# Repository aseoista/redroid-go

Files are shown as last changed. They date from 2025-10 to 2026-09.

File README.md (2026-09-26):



> [!WARNING]
> In every commit and release before [0a4a438](https://github.com/aseoista/redroid-go/commit/0a4a438) (including **v1.0.2**), transistor **Q2** was connected in reverse. You should **build the device from the _master_ branch**, where this is fixed, until a new release is issued.

REDROID-GO is an open-source, custom-designed handheld gaming console inspired by the original ODROID-GO. This project enhances the original (discontinued) design with modern features, while maintaining as much as possible software compatibility.

|  | redroid_go_front | redroid_go_bottom |
| :---: | :---: | :---: |
| Full Build | PCB Front  | PCB Back | 

## Features
- **USB-C Connector** – Modern power and data connectivity.
- **Optional IPS Display** – Upgrade to a vibrant IPS screen instead of the standard TFT.
- **High Software Compatibility** – Works with ODROID-GO software, but unfortunately some patches may be required, see below.
- **Fully Open-Source** ❤️ – Schematics, PCB, and BOM included!

## Repository Contents
- **KiCad Project** – Includes schematic, PCB design, and layout.
- **FreeCAD Project** – Design of the shell.
- **Bill of Materials (BOM)** – All of the PCB components are sourced from LCSC. Other components, such as the display, speaker, battery, buttons need to be bought separately.

### Branching Structure
The _master_ branch contains the latest, **unstable** version of the project, which has not been manufactured or tested yet. If you are looking for a stable and tested version, please refer to the **releases** section, where you can find previous working versions of REDROID-GO.

## Compatibility
The base idea is to keep the project as much software-compatible as possible to the original ODROID-GO. There are some caveats though:
- New ESP32-WROVERs require the setting `CONFIG_INT_WDT` set to `y` in ESP-IDF.
- When using the IPS display, the commands to initialize it should include an additional `0x21`. This is because even if the IPS display uses the same driver IC as the TFT one, by default the colors are inverted.

## Hardware Fabrication
For a full guide to build the device, refer to [BUILDING.md](BUILDING.md)!
### Ordering the PCB
You can order the PCB directly from the `gerber.zip` release artifact using any common PCB manufacturer.<br>
Specs for ordering:
- **Thickness:** 1.6 mm, **required** to make it fit in the case
- **Finish:** ENIG is **strongly recommended**. ENIG provides a flatter and more durable pad surface than HASL, which ensures more consistent readings from the membrane buttons over time.

### Soldering the Components
All components can be soldered by hand.

**Tips**
- A regular soldering iron is sufficient — use a **thin tip** for finer control
- Apply **no-clean flux or thermal flux** to ease solder flow and avoid bridges
- **Start with the USB-C connector and the display connector** — they are the most difficult parts to solder; then proceed with the remaining components
- A **desoldering braid** can be very useful to wick away any excess solder or to correct bridges
- When done soldering, clean the PCB with **isopropyl alcohol (≥90% IPA)**, especially around the buttons’ pads, using a brush or lint-free wipe; let it dry fully before powering

### Shell
The shell can be 3D printed using the STL files contained in the `case.zip` release artifact.

## Software
This device can be programmed like any other ESP32-based board.<br>
A customized bootloader is available in this [fork](https://github.com/aseoista/odroid-go-multi-firmware) of the original [odroid-go-multi-firmware](https://github.com/ducalex/odroid-go-multi-firmware).  
For emulation, the recommended firmware is this [fork](https://github.com/aseoista/retro-go) of [retro-go](https://github.com/ducalex/retro-go).

## Contributing
Contributions are welcome! Feel free to submit pull requests or open issues to discuss improvements.

## Acknowledgments
Special thanks to **Hardkernel** for the original ODROID-GO design and the open-source community for keeping retro gaming alive. Thanks also to:
 -  [32teeth](https://github.com/32teeth) for the membrane buttons library.
 -  [DoganM95](https://github.com/DoganM95) and [snakeye](https://github.com/snakeye) for references on USB PD resistors and auto programming of the ESP32 (see [CH340C-Serial-Programmer](https://github.com/DoganM95/CH340C-Serial-Programmer) and [ch340g-esp32](https://github.com/snakeye/ch340g-esp32)).
 -  [ducalex](https://github.com/ducalex) for providing awesome software for the platform such as _odroid-go-multi-firmware_ and _retro-go_.

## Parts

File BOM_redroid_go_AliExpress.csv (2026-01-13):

Item | “Color” | Quantity | Link
Buttons |  | 1 | https://aliexpress.com/item/1005002768502107.html
Membranes |  | 2 | https://aliexpress.com/item/1005002580982272.html
Display | ILI9341-IPS-No Touch | 1 | https://aliexpress.com/item/1005007431694676.html
Display protection | 6x6cm 10 pcs / 1mm | 1 | https://aliexpress.com/item/4001109161541.html
Screws M2x6mm | M2x6mm | 1 | https://aliexpress.com/item/1005008141974255.html
Screws M2x8mm | M2x8mm | 1 | https://aliexpress.com/item/1005008141974255.html
Speaker | 8R 0.25W 21mm | 1 | https://aliexpress.com/item/1005006344508129.html
Connectors | 10cm/Single head/2p | 1 | https://aliexpress.com/item/1005007277110532.html
LEDs | 5 Color Each 6pcs | 1 | https://aliexpress.com/item/1005006451565935.html
Battery |  | 1 | https://aliexpress.com/item/1005006864773152.html

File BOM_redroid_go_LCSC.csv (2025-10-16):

Reference | Value | Datasheet | Footprint | Qty | DNP | LCSC Part Number
BT1, J3 | Battery_Cell | ~ | Connector_JST:JST_GH_SM02B-GHS-TB_1x02-1MP_P1.25mm_Horizontal | 2 |  | C3029359
C1,C2,C6,C8,C9,C10,C11,C12,C13,C20 | 0.1uF | ~ | Capacitor_SMD:C_0603_1608Metric_Pad1.08x0.95mm_HandSolder | 10 |  | C14663
C3,C7 | 22uF | ~ | Capacitor_SMD:C_0603_1608Metric_Pad1.08x0.95mm_HandSolder | 2 |  | C159801
C4,C5,C16 | 10uF | ~ | Capacitor_SMD:C_0603_1608Metric_Pad1.08x0.95mm_HandSolder | 3 |  | C19702
C14,C15 | 220pF | ~ | Capacitor_SMD:C_0603_1608Metric_Pad1.08x0.95mm_HandSolder | 2 |  | C107081
C17,C18 | 1uF | ~ | Capacitor_SMD:C_0603_1608Metric_Pad1.08x0.95mm_HandSolder | 2 |  | C15849
D1 | D_Schottky | ~ | Diode_SMD:Nexperia_CFP3_SOD-123W | 1 |  | C42441798
F1 | Fuse | ~ | Fuse:Fuse_0603_1608Metric | 1 |  | C41380232
FB1,FB2 | FerriteBead | ~ | Inductor_SMD:L_0603_1608Metric_Pad1.05x0.95mm_HandSolder | 2 |  | C19330
J1 | USB4105-GF-A |  | usb4105:GCT_USB4105-GF-A | 1 |  | C136423
J2 | 5051101892 | 5051101892 | CON_5051101892_MOL | 1 |  | C3249996
J4 | Conn_01x10_Pin | ~ | Connector_PinSocket_2.54mm:PinSocket_1x10_P2.54mm_Horizontal | 1 |  | C2897392
L1 | 1uH | ~ | Inductor_SMD:L_Murata_LQH2MCNxxxx02_2.0x1.6mm | 1 |  | C598616
PAM8304 | PAM8304 |  | Package_SO:MSOP-8_3x3mm_P0.65mm | 1 |  | C581342
Q1,Q3 | UMH3N | http://rohmfs.rohm.com/en/products/databook/datasheet/discrete/transistor/digital/emh3t2r-e.pdf | Package_TO_SOT_SMD:SOT-363_SC-70-6_Handsoldering | 2 |  | C62892
Q2 | PMOS | https://ngspice.sourceforge.io/docs/ngspice-html-manual/manual.xhtml#cha_MOSFETs | Package_TO_SOT_SMD:SOT-23 | 1 |  | C7422949
R1,R2 | 5.1k | ~ | Resistor_SMD:R_0603_1608Metric_Pad0.98x0.95mm_HandSolder | 2 |  | C881139
R3,R9,R10,R11,R12,R13,R14,R22,R23 | 100k | ~ | Resistor_SMD:R_0603_1608Metric_Pad0.98x0.95mm_HandSolder | 9 |  | C14675
R4 | 200k | ~ | Resistor_SMD:R_0603_1608Metric_Pad0.98x0.95mm_HandSolder | 1 |  | C49965
R5 | 44k2 | ~ | Resistor_SMD:R_0603_1608Metric_Pad0.98x0.95mm_HandSolder | 1 |  | C2930103
R6,R8,R18 | 2k | ~ | Resistor_SMD:R_0603_1608Metric_Pad0.98x0.95mm_HandSolder | 3 |  | C2907137
R7,R15,R16,R17,R20 | 10k | ~ | Resistor_SMD:R_0603_1608Metric_Pad0.98x0.95mm_HandSolder | 5 |  | C98220
R19,R24,R25,R26 | 21R | ~ | Resistor_SMD:R_0603_1608Metric_Pad0.98x0.95mm_HandSolder | 4 |  | C403071
SW11 | SW_SPDT | ~ | MK-12F03-G015:MK-12F03-G015 | 1 |  | C963208
U1 | ESP32-WROVER-E-N16R8 | ESP32-WROVER-E-N16R8 | ESP32-WROVER-E_EXP | 1 |  | C529589
U2 | CH340C | https://datasheet.lcsc.com/szlcsc/Jiangsu-Qin-Heng-CH340C_C84681.pdf | Package_SO:SOIC-16_3.9x9.9mm_P1.27mm | 1 |  | C84681
U3 | MP2161GJ-Z | MP2161GJ-Z | TSOT23-8_MP2161_MNP | 1 |  | C3003189
U4 | XC6802A42XMR-G | XC6802A42XMR-G | XC6802A42XMR:SOP_XC6802_TOR | 1 |  | C160463
U5 | XC6206PxxxMR | https://www.torexsemi.com/file/xc6206/XC6206.pdf | Package_TO_SOT_SMD:SOT-23-3 | 1 |  | C5252899
U6 | uSD |  | SOFNG:SOFNG_TF-15x15 | 1 |  | C111196
U7,U8,U9 | NC7SZ125M5X | https://www.onsemi.com/pdf/datasheet/nc7sz125-d.pdf | Package_TO_SOT_SMD:SOT-23-5_HandSoldering | 3 |  | C7420

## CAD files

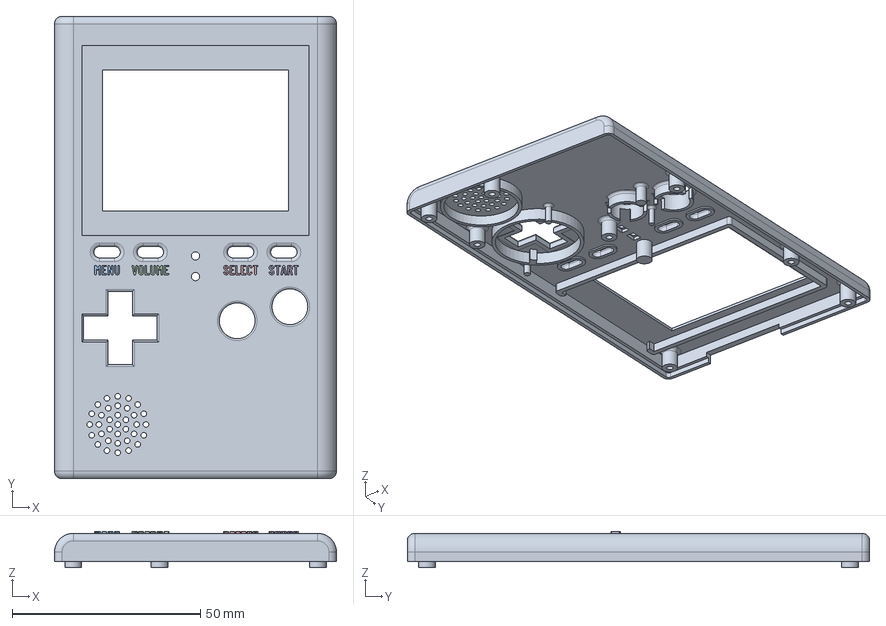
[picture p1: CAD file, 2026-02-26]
case/redroid_go.FCStd
75.0 x 123.0 x 9.60 mm
front
volume_ss
menu_e
volume_e
select_e
start_e

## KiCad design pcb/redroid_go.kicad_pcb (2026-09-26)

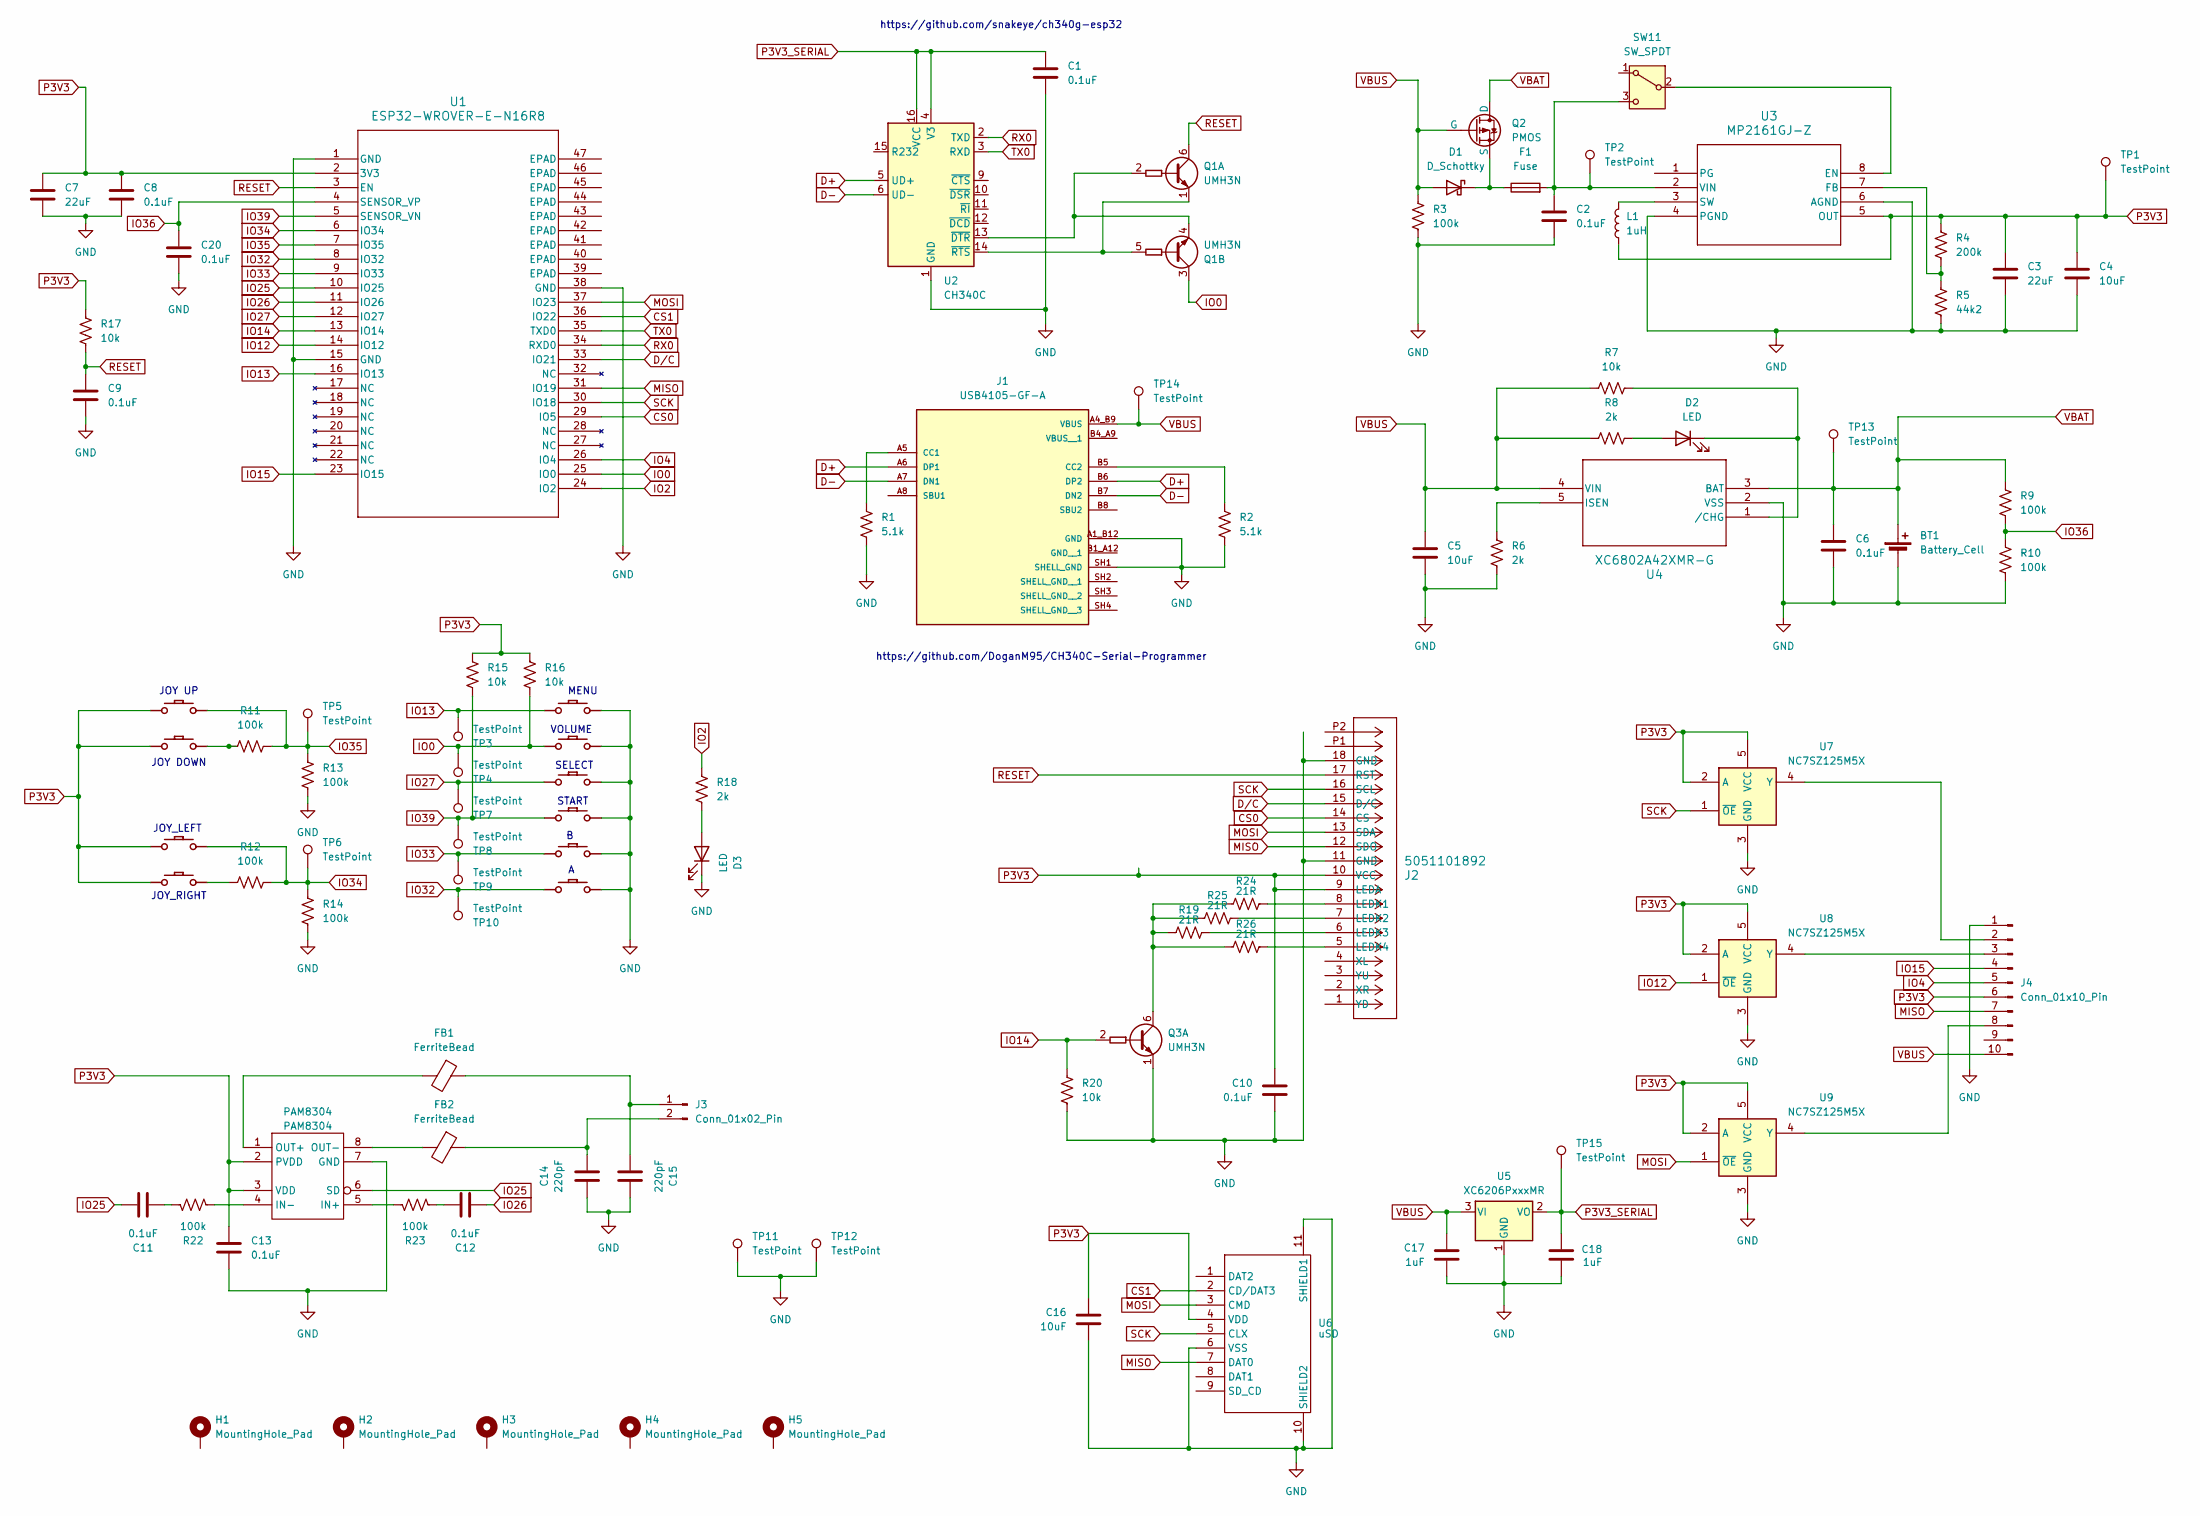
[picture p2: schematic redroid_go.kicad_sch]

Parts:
BT1: Battery_Cell; JST_GH_SM02B-GHS-TB_1x02-1MP_P1.25mm_Horizontal
C1, C2, C6, C8, C9, C10, C11, C12, C13, C20: 0.1uF; C_0603_1608Metric_Pad1.08x0.95mm_HandSolder
C3, C7: 22uF; C_0603_1608Metric_Pad1.08x0.95mm_HandSolder
C4, C5, C16: 10uF; C_0603_1608Metric_Pad1.08x0.95mm_HandSolder
C14, C15: 220pF; C_0603_1608Metric_Pad1.08x0.95mm_HandSolder
C17, C18: 1uF; C_0603_1608Metric_Pad1.08x0.95mm_HandSolder
D1: D_Schottky; Nexperia_CFP3_SOD-123W
D2, D3: LED; LED_D3.0mm
F1: Fuse; Fuse_0603_1608Metric
FB1, FB2: FerriteBead; L_0603_1608Metric_Pad1.05x0.95mm_HandSolder
H1, H2, H3, H4, H5: MountingHole_Pad; MountingHole_2.2mm_M2_DIN965_Pad
J1: USB4105-GF-A; GCT_USB4105-GF-A; PARTREV B4
J2: 5051101892; CON_5051101892_MOL
J3: Conn_01x02_Pin; JST_GH_SM02B-GHS-TB_1x02-1MP_P1.25mm_Horizontal
J4: Conn_01x10_Pin; PinSocket_1x10_P2.54mm_Horizontal
L1: 1uH; L_Murata_LQH2MCNxxxx02_2.0x1.6mm
PAM8304: PAM8304; MSOP-8_3x3mm_P0.65mm
Q1, Q3: UMH3N; SOT-363_SC-70-6_Handsoldering
Q2: PMOS; SOT-23
R1, R2: 5.1k; R_0603_1608Metric_Pad0.98x0.95mm_HandSolder
R3, R9, R10, R11, R12, R13, R14, R22, R23: 100k; R_0603_1608Metric_Pad0.98x0.95mm_HandSolder
R4: 200k; R_0603_1608Metric_Pad0.98x0.95mm_HandSolder
R5: 44k2; R_0603_1608Metric_Pad0.98x0.95mm_HandSolder
R6, R8, R18: 2k; R_0603_1608Metric_Pad0.98x0.95mm_HandSolder
R7, R15, R16, R17, R20: 10k; R_0603_1608Metric_Pad0.98x0.95mm_HandSolder
R19, R24, R25, R26: 21R; R_0603_1608Metric_Pad0.98x0.95mm_HandSolder
SW1: UP; CONDUCTIVE_BUTTON_DIRECTIONAL_THICK
SW2: DOWN; CONDUCTIVE_BUTTON_DIRECTIONAL_THICK
SW3: LEFT; CONDUCTIVE_BUTTON_DIRECTIONAL_THICK
SW4: RIGHT; CONDUCTIVE_BUTTON_DIRECTIONAL_THICK
SW5: MENU; CONDUCTIVE_BUTTON_STARTSELECT
SW6: VOLUME; CONDUCTIVE_BUTTON_STARTSELECT
SW7: SELECT; CONDUCTIVE_BUTTON_STARTSELECT
SW8: START; CONDUCTIVE_BUTTON_STARTSELECT
SW9: B; CONDUCTIVE_BUTTON
SW10: A; CONDUCTIVE_BUTTON
SW11: SW_SPDT; MK-12F03-G015
TP1, TP2, TP3, TP4, TP5, TP6, TP7, TP8, TP9, TP10, TP11, TP12, TP13, TP14, TP15: TestPoint; TestPoint_Pad_D1.5mm
U1: ESP32-WROVER-E-N16R8; ESP32-WROVER-E_EXP
U2: CH340C; SOIC-16_3.9x9.9mm_P1.27mm
U3: MP2161GJ-Z; TSOT23-8_MP2161_MNP
U4: XC6802A42XMR-G; SOP_XC6802_TOR
U5: XC6206PxxxMR; SOT-23-3
U6: uSD; SOFNG_TF-15x15
U7, U8, U9: NC7SZ125M5X; SOT-23-5_HandSoldering

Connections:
CS0: J2.14 (CS), U1.29 (IO5)
CS1: U1.36 (IO22), U6.2 (CD/DAT3)
D+: J1.A6 (DP1), J1.B6 (DP2), U2.5 (UD+)
D-: J1.A7 (DN1), J1.B7 (DN2), U2.6 (UD-)
GND: BT1.2 (-), C1.2, C2.2, C3.2, C4.2, C5.2, C6.2, C7.2, C8.2, C9.2, C10.2, C13.2, C14.1, C15.1, C16.2, C17.2, C18.2, C20.2, D3.1 (K), J1.A1_B12 (GND), J1.SH1 (SHELL_GND), J2.11 (GND), J2.18 (GND), J4.1, PAM8304.7 (GND), Q3.1 (E1), R1.2, R2.2, R3.2, R5.2, R6.2, R10.2, R13.1, R14.1, R20.2, SW5.P$GND, SW6.P$GND, SW7.P$GND, SW8.P$GND, SW9.P$GND, SW10.P$GND, TP11.1 (1_1), TP12.1 (1_1), U1.1 (GND), U1.15 (GND), U1.38 (GND), U2.1 (GND), U3.4 (PGND), U3.6 (AGND), U4.2 (VSS), U5.1 (GND), U6.6 (VSS), U6.10 (SHIELD2), U6.11 (SHIELD1), U7.3 (GND), U8.3 (GND), U9.3 (GND)
IO0: Q1.3 (C2), R16.1, SW6.P$ACTIVE, TP4.1 (1_1), U1.25 (IO0)
IO2: R18.2, U1.24 (IO2)
IO4: J4.5, U1.26 (IO4)
IO12: U1.14 (IO12), U8.1 (~OE)
IO13: SW5.P$ACTIVE, TP3.1 (1_1), U1.16 (IO13)
IO14: Q3.2 (B1), R20.1, U1.13 (IO14)
IO15: J4.4, U1.23 (IO15)
IO25: C11.2, PAM8304.6 (SD), U1.10 (IO25)
IO26: C12.1, U1.11 (IO26)
IO27: SW7.P$ACTIVE, TP7.1 (1_1), U1.12 (IO27)
IO32: SW10.P$ACTIVE, TP10.1 (1_1), U1.8 (IO32)
IO33: SW9.P$ACTIVE, TP9.1 (1_1), U1.9 (IO33)
IO34: R12.1, R14.2, SW3.P$GND, TP6.1 (1_1), U1.6 (IO34)
IO35: R11.1, R13.2, SW1.P$GND, TP5.1 (1_1), U1.7 (IO35)
IO36: C20.1, R9.2, R10.1, U1.4 (SENSOR_VP)
IO39: R15.1, SW8.P$ACTIVE, TP8.1 (1_1), U1.5 (SENSOR_VN)
MISO: J2.12 (SDO), J4.7, U1.31 (IO19), U6.7 (DAT0)
MOSI: J2.13 (SDA), U1.37 (IO23), U6.3 (CMD), U9.1 (~OE)
unnamed: C11.1, R22.2
unnamed: C12.2, R23.1
unnamed: D1.1 (K), F1.1, Q2.3 (S)
unnamed: D2.2 (A), R8.2
unnamed: D2.1 (K), R7.2, U4.1 (/CHG)
unnamed: D3.2 (A), R18.1
unnamed: J1.A5 (CC1), R1.1
unnamed: J1.B5 (CC2), R2.1
unnamed: J2.8 (LEDK1), R24.2
unnamed: J2.7 (LEDK2), R25.2
unnamed: J2.6 (LEDK3), R19.2
unnamed: J2.5 (LEDK4), R26.2
unnamed: C15.2, FB1.1, J3.1
unnamed: C14.2, FB2.1, J3.2
unnamed: J4.2, U7.4 (Y)
unnamed: J4.3, U8.4 (Y)
unnamed: J4.8, U9.4 (Y)
unnamed: PAM8304.5 (IN+), R23.2
unnamed: PAM8304.4 (IN-), R22.1
unnamed: FB1.2, PAM8304.1 (OUT+)
unnamed: FB2.2, PAM8304.8 (OUT-)
unnamed: Q1.2 (B1), Q1.4 (E2), U2.13 (~DTR)
unnamed: Q1.1 (E1), Q1.5 (B2), U2.14 (~RTS)
unnamed: Q3.6 (C1), R19.1, R24.1, R25.1, R26.1
unnamed: R11.2, SW2.P$GND
unnamed: R12.2, SW4.P$GND
unnamed: SW11.2 (B), U3.8 (EN)
unnamed: C2.1, F1.2, SW11.3 (C), TP2.1 (1_1), U3.2 (VIN)
unnamed: R4.2, R5.1, U3.7 (FB)
unnamed: L1.1, U3.3 (SW)
unnamed: R6.1, U4.5 (ISEN)
P3V3: C3.1, C4.1, C7.1, C8.1, C10.1, C13.1, C16.1, J2.9 (LEDA), J2.10 (VCC), J4.6, L1.2, PAM8304.2 (PVDD), PAM8304.3 (VDD), R4.1, R15.2, R16.2, R17.1, SW1.P$ACTIVE, SW2.P$ACTIVE, SW3.P$ACTIVE, SW4.P$ACTIVE, TP1.1 (1_1), U1.2 (3V3), U3.5 (OUT), U6.4 (VDD), U7.2 (A), U7.5 (VCC), U8.2 (A), U8.5 (VCC), U9.2 (A), U9.5 (VCC)
P3V3_SERIAL: C1.1, C18.1, TP15.1 (1_1), U2.4 (V3), U2.16 (VCC), U5.2 (VO)
RESET: C9.1, J2.17 (RST), Q1.6 (C1), R17.2, U1.3 (EN)
RX0: U1.34 (RXD0), U2.2 (TXD)
SCK: J2.16 (SCL), U1.30 (IO18), U6.5 (CLX), U7.1 (~OE)
TX0: U1.35 (TXD0), U2.3 (RXD)
VBAT: BT1.1 (+), C6.1, Q2.1 (D), R9.1, TP13.1 (1_1), U4.3 (BAT)
VBUS: C5.1, C17.1, D1.2 (A), J1.A4_B9 (VBUS), J4.10, Q2.2 (G), R3.1, R7.1, R8.1, TP14.1 (1_1), U4.4 (VIN), U5.3 (VI)

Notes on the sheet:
VOLUME
SELECT
JOY DOWN
https://github.com/snakeye/ch340g-esp32
MENU
JOY_RIGHT
JOY UP
JOY_LEFT
START
https://github.com/DoganM95/CH340C-Serial-Programmer

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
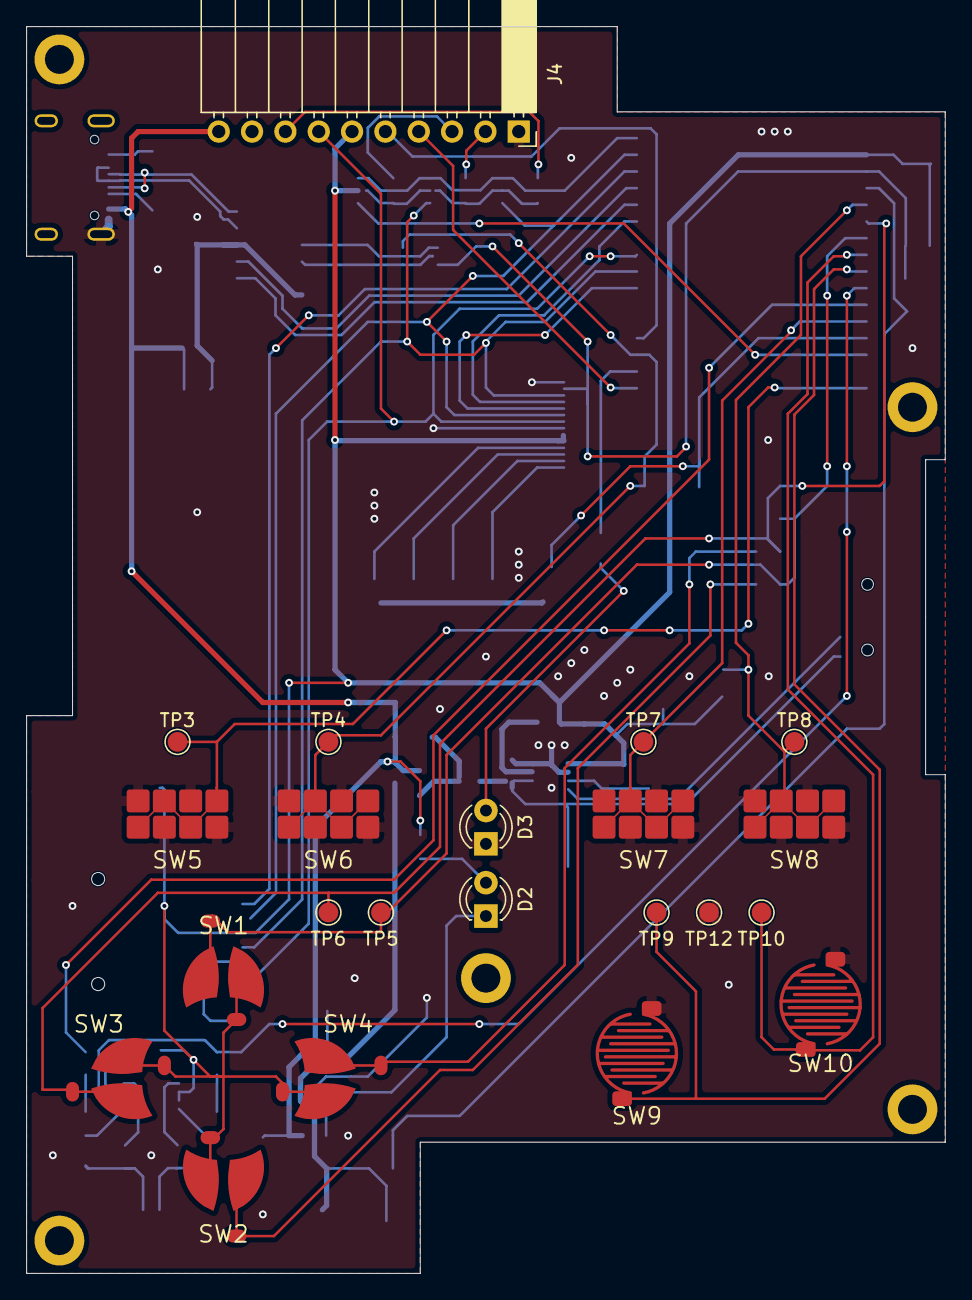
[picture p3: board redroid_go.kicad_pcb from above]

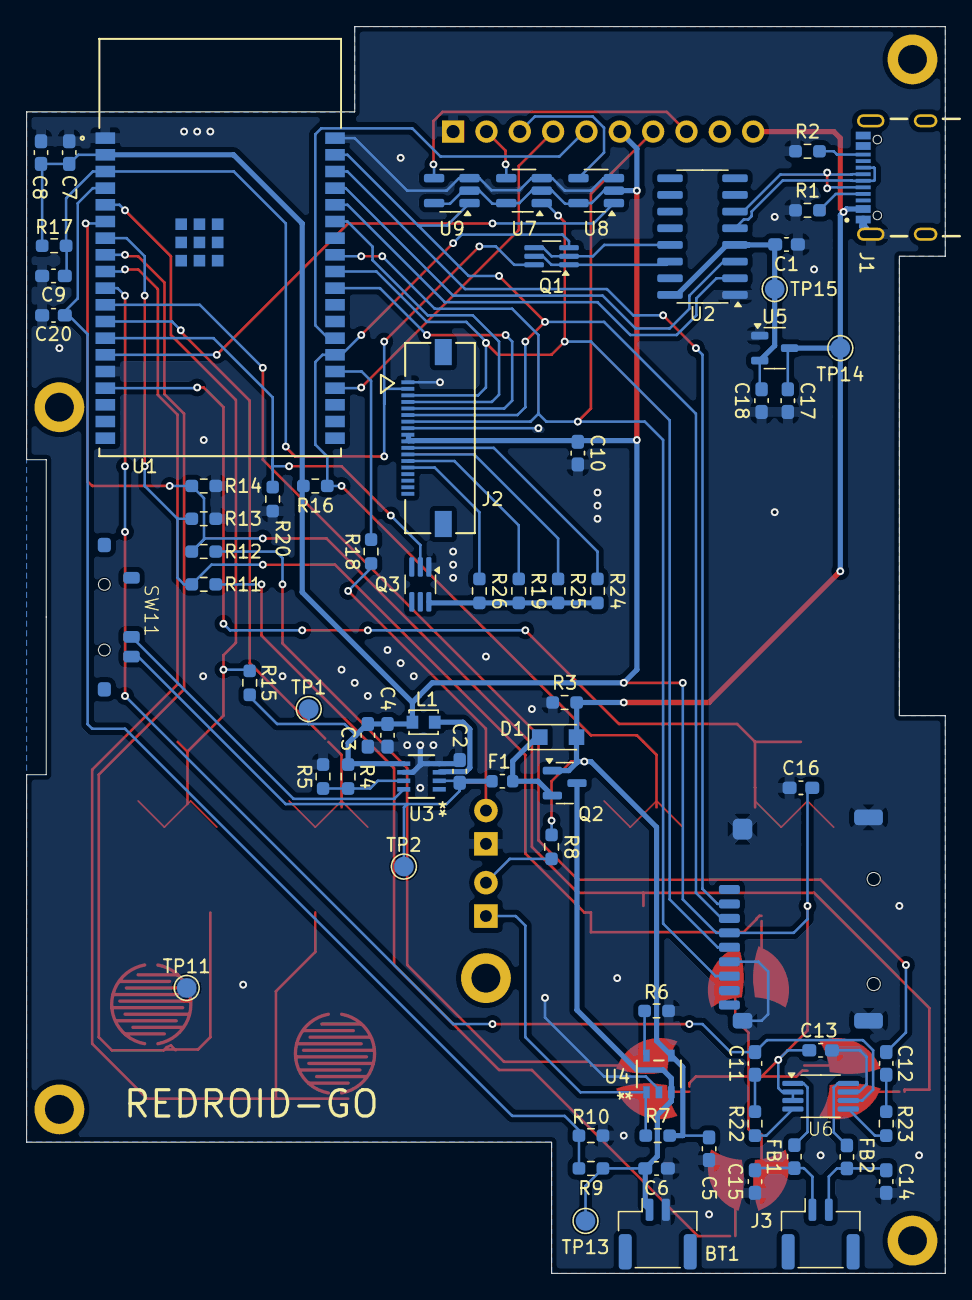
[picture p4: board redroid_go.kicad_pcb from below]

Board: 2 copper layers, 70.0 x 95.0 mm, 100 parts (73 on the bottom side), 63 nets.

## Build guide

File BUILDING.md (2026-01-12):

# Hardware Fabrication


Building a REDROID-GO requires ordering a custom PCB, soldering ~70 components, and 3D printing (or outsourcing) the case.  
All design files are included in the repository (`pcb/` for KiCad, `case/` for FreeCAD) — Gerber & STL files are in the release assets for convenience.

**Estimated build time**  
With all tools and parts ready + intermediate soldering skills → one (rainy) weekend.

## 1. Ordering the PCB

Order the 2-layer PCB using the `gerber.zip` file from the latest release.

**Specifications (mandatory for proper fit):**
- Layers: 2
- Thickness: **1.6 mm** (critical for case fit)
- Surface finish: **ENIG** (strongly recommended) — much better pad flatness and long-term reliability for membrane button contacts than HASL
- Solder mask color: your choice (black looks great!)
- Silkscreen: optional but nice

## 2. Buying the components

Two BOMs (Bill Of Material) are provided:
- `BOM_redroid_go_LCSC.csv` → this is the list of all SMD components required for the board
- `BOM_redroid_go_AliExpress.csv` → additionals parts

## 3. Soldering the Components (Hand-soldering guide)

All parts are hand-solderable — no reflow oven required.
The board has several test points (TPx pads) that make progressive testing easy and strongly recommended.

**Difficulty:** Medium (USB-C & FPC connectors are the hardest parts)

**Recommended tools:**
- Soldering iron with **fine conical tip**
- Solder
- No-clean flux or thermal flux (essential!)
- Desoldering braid
- Isopropyl alcohol (≥90%) (for cleaning)
- Multimeter (for debugging)

**Soldering & testing order (progressive – test at each major stage!)**  
By following this order you minimize risk: if something fails, you know exactly where the problem is and haven't wasted time soldering the whole board yet.

1. **USB-C connector first**  
   Solder the USB-C port carefully (tack one corner pin, check alignment, then solder rest).  
   → **Test:** With a USB cable connected to a charger/PC, measure **~5V** between **TP14 (VBUS)** and **TP11 (GND)**.  
   No voltage → redo solder joints or check cable.

2. **LDO regulator for serial-to-USB converter**  
   Solder the LDO (U5) (and its surrounding capacitors).  
   → **Test:** Apply 5V via USB-C and measure **~3.3V** on **TP15**.  
   No/stable 3.3V → check polarity, bridges, or bad LDO.

3. **CH340 serial-to-USB converter IC**  
   Solder the CH340 + its caps.  
   → **Test:** Connect the board to a PC via USB. It should appear as a new COM port (Windows) or `/dev/ttyUSB*` (Linux/macOS).  
   Try both USB-C orientations — it must work flipped!  
   No recognition or recognition errors → check solder joints on the USB-C connector (on Linux, use `dmesg` to see the kernel logs)
   
5. **Buck converter + power switch**  
   Solder the buck converter IC and its surrounding components.  
   → **Test:** With USB power or battery connected, toggle the power switch and measure **~3.3V** on **TP1**.  
   Correct voltage → proceed safely. Wrong/missing voltage → fix before continuing.

6. **ESP32 module (U1) + reset circuitry**  
   Solder the ESP32 module, its surrounding capacitors, pull-ups/pull-downs, and **Q1** (automatic reset transistor for esptool.py).  
   → **Test:** Connect via USB, open a terminal and run:  
     ```bash
     esptool --port /dev/ttyUSB0 read-mac   # (or COMx on Windows)
     ```
     You should see the ESP32's MAC address. If communication works → great, the core programming path is functional!

7. **Display connector & backlight control**  
    Solder the display FPC connector + related parts (Q3, C10, R20, R26, R19, R25, R24).
    → Flash a simple test firmware (see Software section in the main README).
    If successful, you should see something on the screen.

8. **Remaining components**  
    Now solder the rest (exept the LEDs, see the Assembly section). These are lower risk once the core power/programming/display chain is verified.

**Extra practical tips:**
 - Use tweezers to place small components accurately.
 - Double-check orientation of polarized parts: ICs (notch/dot), diode D1, LEDs, etc. (capacitors used in the project and resistors have no polarity).
 - Solder one pin first, check alignment/flushness, then solder the remaining pins.
 - Tiny component labels are hard to read — use your smartphone camera zoomed in (macro mode helps a lot).
 - After all soldering: clean the entire board thoroughly with IPA (especially button pads) to remove flux residue — this prevents future button contact issues. Let it dry before powering.

**Test Points summary**
| Test Point | Function / Description | Expected Value / Use Case | Typical Measurement Conditions |
|:---:|:---:|:---:|:---:|
| TP1 | 3.3V output from the main buck converter | ≈ 3.3 V (stable when powered on) | Power switch ON, USB or battery connected |
| TP2 | Vin to the buck converter (input voltage) | ≈ 3.7–5.0 V (from battery or USB after diode/switch) | Power applied, before buck conversion, after fuse |
| TP3 | MENU button signal | Pulled high → ~3.3 V idle, drops to 0 V when pressed | Check continuity or voltage change on press |
| TP4 | VOLUME button signal | Pulled high → ~3.3 V idle, drops to 0 V when pressed | Check continuity or voltage change on press |
| TP5 | X-axis | ~0–3.3 V (analog, 0 V idle) | Check continuity or voltage change on press |
| TP6 | Y-axis | ~0–3.3 V (analog, 0 V idle) | Check continuity or voltage change on press |
| TP7 | SELECT button signal | Pulled high → ~3.3 V idle, drops to 0 V when pressed | Check continuity or voltage change on press |
| TP8 | START button signal | Pulled high → ~3.3 V idle, drops to 0 V when pressed | Check continuity or voltage change on press |
| TP9 | B button signal | Pulled high → ~3.3 V idle, drops to 0 V when pressed | Check continuity or voltage change on press |
| TP10 | A button signal | Pulled high → ~3.3 V idle, drops to 0 V when pressed | Check continuity or voltage change on press |
| TP11 | GND (ground reference) | 0 V reference | Use as negative probe reference for all tests |
| TP12 | GND (additional ground reference) | 0 V reference | Extra convenient ground pad |
| TP13 | VBAT (battery voltage) | ≈ 3.7–4.2 V (typical LiPo range) | Battery connected, power switch OFF or ON |
| TP14 | VUSB / VBUS (USB 5V input) | ≈ 4.8–5.2 V | USB cable plugged into charger/PC |
| TP15 | 3.3V output from LDO (for CH340 serial converter) | ≈ 3.3 V (stable when USB powered) | USB connected (before main buck/power switch) |

## 4. 3D Printing the Shell

Use the STL files from the `case.zip` release artifact (or the raw FreeCAD project in `case/` if you want to customize).

**Recommended print settings:**
- Material: **PETG** or **ABS** (PLA is too brittle)
- Layer height: 0.20 mm
- Infill: 20–25%
- Supports: yes for the front part, not required for the rear part
- Wall thickness: at least 3–4 perimeters
- Print orientation: flat on the bed

It is also possible to resin print the shell. Some great results were achieved both by outsourcing the print to commercial external services and with house printers.

Tip: Print the front piece first and test for proper fitting — small scaling errors can ruin assembly.

## 5. Assembly

This is the final stage: putting everything together!

### 5.1 Sharpening / Post-Processing the 3D Prints
3D-printed parts often suffer from the "elephant foot" effect, which can shrink button holes and make movement stiff.

- Test-fit all **buttons** into their sockets in the front shell.
- Check for smooth, friction-free travel when pressed.
- If tight → carefully **sharpen/enlarge** the holes using a **ceramic sharpening tool**, small round file, or hobby knife. Go slowly and test frequently.
- Also check the **LED holes** in the front shell. If too small, gently enlarge them with a **2 mm drill bit**.

### 5.2 Display Protection (Acrylic/plexiglass Panel)
This is the most precise and visible part of the build — take your time.

The recommended acrylic panel (from the BOM) starts at **60 × 60 mm** and needs to be cut to **60 × 50 mm** to fit the front shell recess perfectly.

1. **Do NOT remove** the protective films yet — they protect the surface during cutting and painting.
2. Measure and mark the cutting line accurately (use a metal ruler and fine marker).
3. Cut the panel (knife, fine-tooth saw, or laser if available).
4. Dry-fit the panel into the front shell recess — it should sit flush without gaps.
5. Use the front shell as a jig: with protective film still on, **mark** the exact areas to remain transparent (the display window) using a permanent marker (see example below).
   
7. Carefully cut away and **remove the exterior protective film** (the part outside the marked window).
   
8. **Spray paint** the exposed acrylic surface (black or dark color recommended for best contrast).
    
10. **Do NOT** remove the remaining interior film yet — it keeps the clear window dust-free until final gluing.

### 5.3 Installing the Display
1. Remove the protective film from the display (handle by edges only — avoid touching the active area).
2. Snap-fit the display into its socket in the front shell.
3. Apply small dots of **hot glue** at the corners/edges to secure it.
   
6. Apply **T7000 glue** (or equivalent) around the edges of the recess.
7. Remove the **remaining** internal protective film from the painted acrylic panel and carefully place it. Press gently and evenly — clamp lightly if needed.
8. Let cure (note that T7000 typically needs 24–48 hours for full strength).

### 5.4 Buttons, LEDs & PCB Installation
1. Place the **buttons** — they should sit flush and move freely.
2. Insert the **membrane contacts** into the front shell button sockets.
3. Position the two **LEDs** into their dedicated sockets in the front shell (mind polarity: longer leg = anode).
4. Carefully lower the **PCB** onto the front shell, aligning the screw holes and making sure LEDs enter their sockets properly.
5. Secure the PCB with the **two screws** (highlighted in blue in section 5.6). Use **6mm** length screws.
6. Double-check LED alignment, then **solder** the LED legs to the pads on the PCB.
7. Trim excess LED legs with flush cutters.
8. Connect the display.

### 5.5 Power Switch Modification
Replacement Game Boy Color power switches often come with an adapter that is too tall for REDROID-GO.

1. Cut/modify the adapter plastic part to match the shape shown in the reference picture (usually remove ~2–3 mm from the top/end).
2. Test-fit the modified switch — it should slide smoothly into its slot and actuate correctly.
   

### 5.6 Battery & Speaker
1. Place the **speaker** into its cavity (speaker grille facing outward).
2. Insert the **battery** into its compartment.
3. Connect both to the corresponding connectors on the PCB.
   

### 5.7 Closing the Case
1. Align the rear shell like turning a book page — this helps guide the modified power switch into its hole without bending.
2. Carefully bring the two halves together.
3. Insert and tighten the remaining screws (use **8mm** length screws).
   

Good luck and have fun building your REDROID-GO!

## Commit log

2025-01-26 Initial rearrange
    [redroid_go.kicad_pcb]
2025-01-26 Remove files
    [redroid_go-B_Cu.gbr, redroid_go-B_Mask.gbr, redroid_go-B_Paste.gbr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]
2025-01-26 Minor changes
    [redroid_go.kicad_pcb]
2025-01-26 Fixes in silkscreen
    [redroid_go.kicad_pcb]
2025-01-26 Other fixes in silkscreen
    [redroid_go.kicad_pcb]
2025-01-26 Other minor fixes
    [redroid_go.kicad_pcb]
2025-01-26 Fix esp32 label
    [redroid_go.kicad_pcb]
2025-01-26 Fix via too close to pad
    [redroid_go.kicad_pcb]
2025-01-26 Minor fixes
    [redroid_go.kicad_pcb]
2025-01-27 Fix audo amplifier IC name
    [redroid_go.kicad_sch]
2025-01-29 Update diode footprint
    [redroid_go.kicad_pcb, redroid_go.kicad_sch]
2025-02-08 Change PCB for step down
    [redroid_go.kicad_pcb]
2025-02-08 Made power traces more thick
    [redroid_go.kicad_pcb]
2025-02-08 Minor fix
    [redroid_go.kicad_pcb]
2025-02-08 Remove duplicated resistor in PCB
    [redroid_go.kicad_pcb]
2025-02-08 Fixes in labels
    [redroid_go.kicad_pcb]
2025-02-08 Fix values of some capacitors
    [redroid_go.kicad_pcb, redroid_go.kicad_sch]
2025-02-08 Move labels in PCB
    [redroid_go.kicad_pcb]
2025-02-08 Change L1 PCB footprint
    [redroid_go.kicad_pcb, redroid_go.kicad_sch]
2025-02-09 Reduce required vias
    [redroid_go.kicad_pcb]
2025-02-09 Add BOM for LCSC
    [BOM_redroid_go_LCSC.csv]
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2025-02-09 Fix drill command in CI
2025-02-09 Add project name label
    [redroid_go.kicad_pcb]
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2025-02-09 Update BOM
    [BOM_redroid_go_LCSC.csv]
2025-02-11 Flip side of LED, fix position of test pad
    [redroid_go.kicad_pcb]
2025-03-10 Convert to KiCad 9
    [redroid_go.kicad_pcb, redroid_go.kicad_sch]
2025-03-11 Fix battery/VBUS PMOS polarity
    [redroid_go.kicad_pcb, redroid_go.kicad_sch]
2025-03-11 Add separate power for serial chip
    [BOM_redroid_go_LCSC.csv, redroid_go.kicad_pcb, redroid_go.kicad_sch]
2025-03-11 Minor fix in via
    [redroid_go.kicad_pcb]
2025-03-11 Move SD card connector
    [redroid_go.kicad_pcb]
2025-03-12 Change 3v3 LDO to AMS1117 and add test point
    [redroid_go.kicad_pcb, redroid_go.kicad_sch]
2025-03-12 Minor fix in PCB labels
    [redroid_go.kicad_pcb]
2025-03-12 Cleanup tracks and vias
    [redroid_go.kicad_pcb]
2025-03-14 Remove solder paste in buttons
    [redroid_go.kicad_pcb]
2025-03-14 Remove paste in menu buttons
    [redroid_go.kicad_pcb]
2025-03-14 Update menu button footprints
    [redroid_go.kicad_pcb]
2025-03-14 Fix board display margin
    [redroid_go.kicad_pcb]
2025-03-14 Fix ISEN resistor in battery charger
    [BOM_redroid_go_LCSC.csv, redroid_go.kicad_sch]
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2025-03-15 Add missing via
    [redroid_go.kicad_pcb]
2025-03-16 Update audio out filter capacitors
    [BOM_redroid_go_LCSC.csv, redroid_go.kicad_sch]
2025-03-16 Fix 3V3_SERIAL capacitors
    [BOM_redroid_go_LCSC.csv, redroid_go.kicad_pcb, redroid_go.kicad_sch]
2025-03-16 Minor fixes in PCB
    [redroid_go.kicad_pcb]
2025-03-29 Move SD socket
    [redroid_go.kicad_pcb]
2025-04-13 Move display connector and minor fixes
    [redroid_go.kicad_pcb]
2025-04-13 Add new mouting hole
    [redroid_go.kicad_pcb, redroid_go.kicad_sch]
2025-04-22 Change DPAD resistors
    [BOM_redroid_go_LCSC.csv, redroid_go.kicad_pcb, redroid_go.kicad_sch]
2025-05-10 Rename label
    [redroid_go.kicad_sch]
2025-05-10 Fix filled zones
    [redroid_go.kicad_pcb]
2025-05-10 Move menu buttons
    [redroid_go.kicad_pcb]
2025-05-10 Change serial LDO to SOT23-3 and update BOM
    [BOM_redroid_go_LCSC.csv, redroid_go.kicad_pcb, redroid_go.kicad_sch]
2025-05-15 Adjust DPAD and menu buttons pad position
    [redroid_go.kicad_pcb]
2025-05-15 Improve A and B buttons pads
    [redroid_go.kicad_pcb]
2025-05-26 Relocate components
    [redroid_go.kicad_pcb]
2025-05-27 Minor fixes in F.Silkscreen
    [redroid_go.kicad_pcb]
2025-05-27 Move test pads
    [redroid_go.kicad_pcb]
2025-05-27 Improve charge LED resistor
    [redroid_go.kicad_pcb]
2025-05-28 Various fixes
    [redroid_go.kicad_pcb]
2025-05-29 Integrate feedback from JLCDFM
    [redroid_go.kicad_pcb]
2025-06-01 Update 3v3 trace
    [redroid_go.kicad_pcb]
2025-06-02 Improve symmetry of audio components
    [redroid_go.kicad_pcb]
2025-08-13 Move PCB-related files in folder
    [redroid_go.kicad_pcb, redroid_go.kicad_sch]
2025-08-13 Add initial case
    [redroid_go.FCStd]
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2025-08-13 Fix STL wf
2025-08-14 Add missing GND connectio to ESP32
    [redroid_go.kicad_pcb, redroid_go.kicad_sch]
2025-08-14 Move charge led
    [redroid_go.kicad_pcb]
2025-08-14 Improve LED layout
    [redroid_go.kicad_pcb]
2025-08-14 Change led orientation
    [redroid_go.kicad_pcb]
2025-08-14 Improvements in vias
    [redroid_go.kicad_pcb]
2025-08-14 Change pcb for improved power switch
    [redroid_go.kicad_pcb]
2025-08-14 Add BOM for aliexpress sourced parts
    [BOM_redroid_go_aliexpress.csv]
2025-08-17 Fix switch hole size
    [redroid_go.kicad_pcb]
2025-08-21 Move switch again
    [redroid_go.kicad_pcb]
2025-08-27 Other fix in switch position
    [redroid_go.kicad_pcb]
2025-08-27 Change switch connection to improve PCB
    [redroid_go.kicad_pcb, redroid_go.kicad_sch]
2025-08-28 Minor fixes in silkscreen
    [redroid_go.kicad_pcb]
2025-08-28 Move menu buttons up
    [redroid_go.kicad_pcb]
2025-08-31 Update case front
    [redroid_go.FCStd]
2025-10-05 Updata case back to support switch
    [redroid_go.FCStd]
2025-10-16 Enlarge switch hole
    [redroid_go.FCStd]
2025-10-16 Enlarge GPIO header hole
    [redroid_go.FCStd]
2025-10-16 Add missing value for some components
    [redroid_go.kicad_sch]
2025-10-16 Update LCSC BOM
    [BOM_redroid_go_LCSC.csv]
2025-10-22 Add hardware fabrication details to README
    Added hardware fabrication section with PCB ordering and soldering tips.
2025-10-22 Add shell 3D printing instructions to README
    Added instructions for 3D printing the shell using STL files.
2025-10-22 Revise repository contents in README
    Updated README to include FreeCAD project and removed assembly instructions note.
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2025-10-23 Add battery in BOM and fix extension
    [BOM_redroid_go_AliExpress.csv]
2025-10-24 Revise README images
    Updated image layout in README and add device image.
2025-12-29 Move dpad down
    [redroid_go.FCStd]
2025-12-29 Increase width to allow resin prints
    [redroid_go.FCStd]
2025-12-29 Decrease GPIO header socket height
    [redroid_go.FCStd]
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2026-01-11 Fix path for schematic file export in CI workflow
2026-01-13 Fix AliExpress BOM
    [BOM_redroid_go_AliExpress.csv]
2026-01-28 Adjust length of back's screw pads
    [redroid_go.FCStd]
2026-01-28 Reduced length of back's screw pads
    [redroid_go.FCStd]
2026-02-01 Add button labels
    [redroid_go.FCStd]
2026-02-15 Minoor improvement in position of A button
    [redroid_go.FCStd]
2026-02-15 Remove unuseful pocket in case
    [redroid_go.FCStd]
2026-02-24 Adjust position of USB pocket
    [redroid_go.FCStd]
2026-02-24 Fix dpad position
    [redroid_go.FCStd]
2026-02-24 Increase heigth of dpad socket
    [redroid_go.FCStd]
2026-02-26 Minor improvements in dpad holders
    [redroid_go.FCStd]
2026-07-26 Update KiCad project to version 10
    [redroid_go.kicad_pcb, redroid_go.kicad_sch]
2026-07-26 Update CI workflows to latest actions and pinned Ubuntu LTS runner
    Bump actions to their current major versions: actions/checkout v3 -> v7,
    actions/upload-artifact v4 -> v7, softprops/action-gh-release v2 -> v3.
    Pin the runner to ubuntu-24.04 instead of the floating ubuntu-latest so a
    runner rollover cannot silently change the toolchain. 24.04 is the latest
    GA Ubuntu LTS image; ubuntu-26.04 is still preview-only and has no FreeCAD
    PPA build.
    Also fix two issues that kept these workflows from working:
    - Bump the KiCad PPA from 9.0 to 10.0. The project was migrated to KiCad 10
    in 3a64fe1, and a v9 kicad-cli cannot open v10 files.
    - Trigger on master rather than main. master is the default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
2026-09-26 Fix Q2 polarity
    [redroid_go.kicad_pcb, redroid_go.kicad_sch]
